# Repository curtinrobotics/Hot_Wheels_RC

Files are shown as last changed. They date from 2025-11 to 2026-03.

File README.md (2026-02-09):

# Hot_Wheels_RC

Welcome to the **Hot Wheels** project for Curtin Robotics club (CRoC)

This repository contains Arduino, ESP32, C++ codebases, hardware design, mechanical/electrical schematics.

---

## Project Structure

```
Hot_Wheels_RC/
├── archive/                    -> archival assests, may be still relevant
├── docs/                       -> Documentation for the project
├── hardware_design/            -> CAD and schematic files for the hardware components
│   ├── Hot_Wheels_3d_model/    -> 3D model exported files (e.g., .stl, .step) for manufacturing and prototyping
│   └── Hot_Wheels_3d_model.f3d -> Fusion 360 CAD file (requires Fusion 360 to open)
├── Hot_Wheels_arduino_firmware/ -> Arduino firmware source code
```

## Collaboration Guidelines

To ensure smooth teamwork:

- **Commit, pull, and push frequently** to keep everyone on the same page.
- **Create a branch** for any experimental or testing-specific changes. Once stable, we can discuss merging them into the main codebase.
- If you have questions, feel free to reach out to Aron or Joshan

---

Contributors:  
- **Shea, Aron**

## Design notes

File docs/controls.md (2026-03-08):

# Controls

Left joystick (left and right): steering left and right

RT/R3: accelerate

LT/L3: reverse

Steering trim

LB/L1: trim left

RB/R1: trim right

D-pad up: reset trim

LB/L1 + RB/R1 + D-pad up: factory reset saved trim

*Note: steering trim is saved and restored after reboot.*

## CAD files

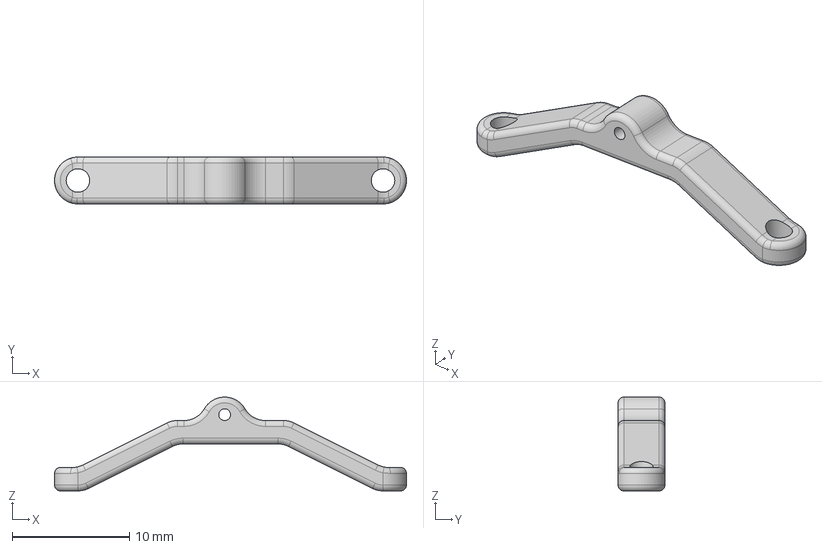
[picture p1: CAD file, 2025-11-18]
hardware_design/Hot_Wheels_3d_model/TieRod.step
30.0 x 4.00 x 8.00 mm

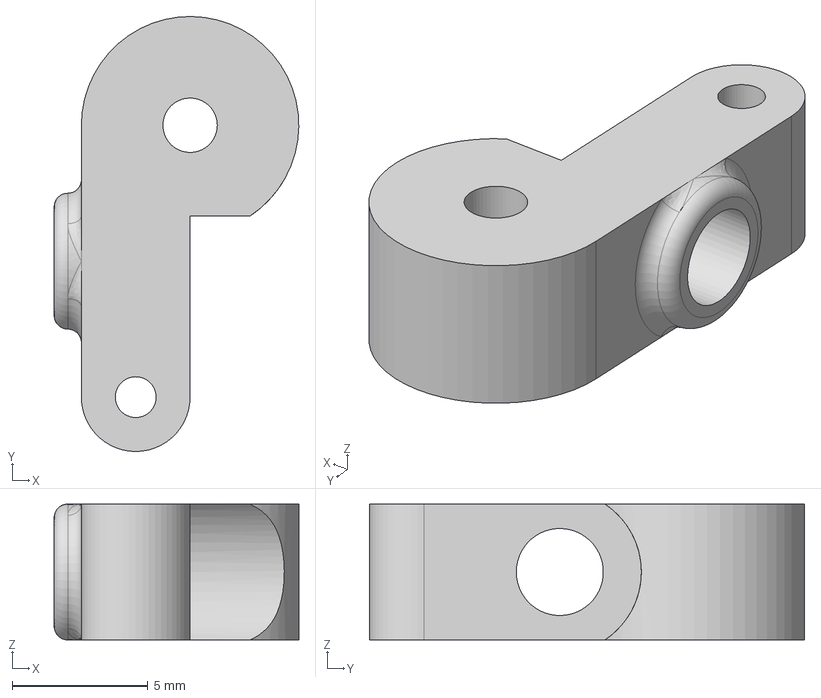
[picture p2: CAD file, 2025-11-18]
hardware_design/Hot_Wheels_3d_model/SteeringKnuckle.step
9.00 x 16.0 x 5.00 mm

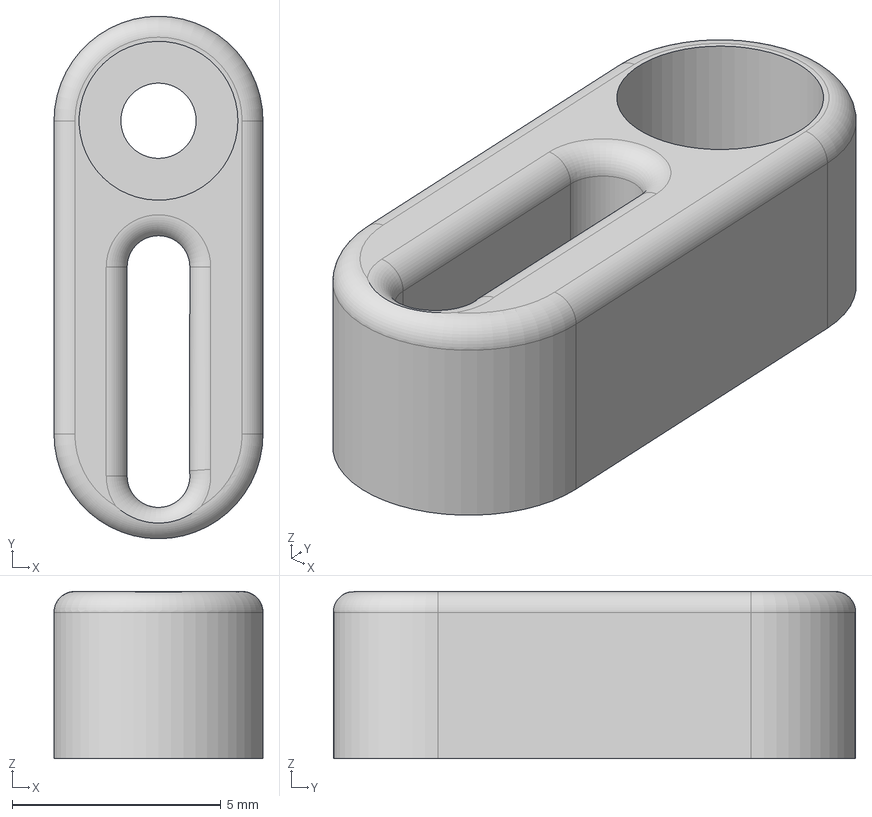
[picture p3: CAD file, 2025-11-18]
hardware_design/Hot_Wheels_3d_model/ServoArm.step
5.00 x 12.5 x 4.00 mm

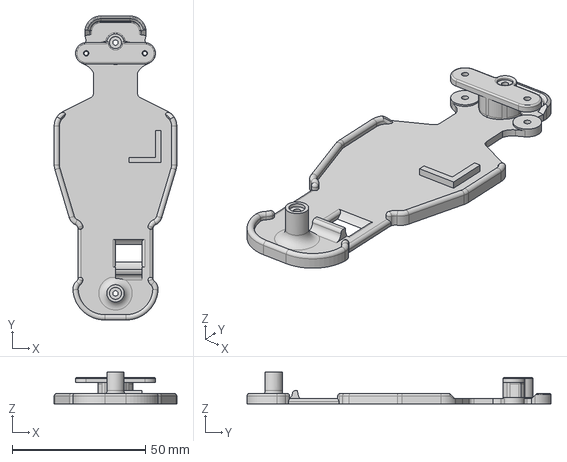
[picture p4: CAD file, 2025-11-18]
hardware_design/Hot_Wheels_3d_model/Body.step
46.0 x 114.0 x 12.0 mm

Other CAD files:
hardware_design/Hot_Wheels_3d_model.f3d

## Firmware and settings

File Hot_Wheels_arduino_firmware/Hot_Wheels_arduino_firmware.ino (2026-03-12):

#include <Bluepad32.h>
#include <Preferences.h>

Preferences prefs;
const char* NVS_NAMESPACE = "hwrc";
const char* NVS_KEY_STEER_TRIM = "trim";

const int servoPin = 9;
const int Forward = 12;
const int Back = 11;

// PWM Configuration for motors
const int PWM_FREQ = 5000;     // 5 KHz PWM frequency for motors
const int PWM_RESOLUTION = 8;  // 8-bit resolution (0-255)
const int FORWARD_PWM_CHANNEL = 0;
const int BACK_PWM_CHANNEL = 1;

// PWM Configuration for servo
const int SERVO_PWM_CHANNEL = 2;
const int SERVO_PWM_FREQ = 50;        // 50 Hz for standard servo
const int SERVO_PWM_RESOLUTION = 14;  // 14-bit for servo control

ControllerPtr myController = nullptr;
int Drive = 0;
int Reverse = 0;
int angle = 90;

// --- Steering trim (LB/RB) ---
int STEERING_TRIM_DEG = 0;          // applied to steering angle (degrees)
const int TRIM_STEP_DEG = 1;       // change per button press
const int TRIM_LIMIT_DEG = 90;     // max +/- trim from center
const bool TRIM_LATCH_START_STATE = false; // set both latches true/false at start

// Setup TRIM latch
bool lastTrimLB = TRIM_LATCH_START_STATE;
bool lastTrimRB = TRIM_LATCH_START_STATE;
bool lastDpadUp = TRIM_LATCH_START_STATE;
bool lastTrimFactoryResetCombo = TRIM_LATCH_START_STATE;

const int DEADZONE = 30;
const int SPEED_LIMIT_PERCENT = 100;  // Limit speed to 40% of max

// Trigger threshold and mapping
const int TRIGGER_DEADZONE = 10;
const int TRIGGER_MAX = 1023;

// Servo pulse timing (in microseconds)
const int SERVO_MIN_US = 1000;
const int SERVO_MAX_US = 2000;

// Steering limit (degrees from center=90). Example: 30 -> range 60..120
const int STEER_LIMIT_DEG = 90;

static void loadSteeringTrim() {
  STEERING_TRIM_DEG = prefs.getInt(NVS_KEY_STEER_TRIM, 0);
  STEERING_TRIM_DEG = constrain(STEERING_TRIM_DEG, -TRIM_LIMIT_DEG, TRIM_LIMIT_DEG);
  Serial.printf("Loaded steering trim: %+d deg\n", STEERING_TRIM_DEG);
}

static void saveSteeringTrim() {
  STEERING_TRIM_DEG = constrain(STEERING_TRIM_DEG, -TRIM_LIMIT_DEG, TRIM_LIMIT_DEG);
  prefs.putInt(NVS_KEY_STEER_TRIM, STEERING_TRIM_DEG);
}

void onConnectedController(ControllerPtr ctl) {
  if (myController == nullptr) {
    Serial.print("CALLBACK: Controller is connected, index=");
    Serial.println(ctl->index());
    myController = ctl;

    // Initialize trim latch state on connect
    lastTrimLB = TRIM_LATCH_START_STATE;
    lastTrimRB = TRIM_LATCH_START_STATE;
    lastDpadUp = TRIM_LATCH_START_STATE;
    lastTrimFactoryResetCombo = TRIM_LATCH_START_STATE;

    ctl->setColorLED(0, 255, 0);
  }
}

void onDisconnectedController(ControllerPtr ctl) {
  if (myController == ctl) {
    Serial.print("CALLBACK: Controller is disconnected from index=");
    Serial.println(ctl->index());

    angle = 90;

    // Initialize trim latch state on connect
    lastTrimLB = TRIM_LATCH_START_STATE;
    lastTrimRB = TRIM_LATCH_START_STATE;
    lastDpadUp = TRIM_LATCH_START_STATE;
    lastTrimFactoryResetCombo = TRIM_LATCH_START_STATE;

    // Stop motors when controller disconnects
    ledcWrite(FORWARD_PWM_CHANNEL, 0);
    ledcWrite(BACK_PWM_CHANNEL, 0);

    // Center servo
    setServoAngle(90);

    myController = nullptr;
  }
}

void processController() {
  if (myController && myController->isConnected() && myController->hasData()) {
    int32_t axisX = myController->axisX();
    int32_t throttle = myController->throttle();
    int32_t brake = myController->brake();

    // --- Steering trim via bumpers (edge-triggered) ---
    const bool lb = myController->l1();  // LB/L1
    const bool rb = myController->r1();  // RB/R1

    // D-pad up resets trim (edge-triggered)
    const bool dpadUp = (myController->dpad() & DPAD_UP) != 0;

    // Factory reset combo: LB + RB + D-pad Up clears saved trim (edge-triggered)
    const bool trimFactoryResetCombo = lb && rb && dpadUp;

    bool trimChanged = false;

    if (trimFactoryResetCombo && !lastTrimFactoryResetCombo) {
      STEERING_TRIM_DEG = 0;
      prefs.remove(NVS_KEY_STEER_TRIM);
      Serial.println("Steering trim factory reset: cleared saved value");
    } else {

      if (lb && !lastTrimLB) {
        STEERING_TRIM_DEG += TRIM_STEP_DEG;
        STEERING_TRIM_DEG = constrain(STEERING_TRIM_DEG, -TRIM_LIMIT_DEG, TRIM_LIMIT_DEG);
        Serial.printf("Steering trim: %+d deg\n", STEERING_TRIM_DEG);
        trimChanged = true;
      }
      if (rb && !lastTrimRB) {
        STEERING_TRIM_DEG -= TRIM_STEP_DEG;
        STEERING_TRIM_DEG = constrain(STEERING_TRIM_DEG, -TRIM_LIMIT_DEG, TRIM_LIMIT_DEG);
        Serial.printf("Steering trim: %+d deg\n", STEERING_TRIM_DEG);
        trimChanged = true;
      }

      if (dpadUp && !lastDpadUp) {
        STEERING_TRIM_DEG = 0;
        Serial.println("Steering trim reset: 0 deg");
        trimChanged = true;
      }

      if (trimChanged) {
        saveSteeringTrim();
      }
    }

    lastTrimLB = lb;
    lastTrimRB = rb;
    lastDpadUp = dpadUp;
    lastTrimFactoryResetCombo = trimFactoryResetCombo;

    if (abs(axisX) < DEADZONE) {
      axisX = 0;
    }

    Drive = throttle;
    Reverse = brake;

    const int leftLimit = 90 + STEER_LIMIT_DEG;
    const int rightLimit = 90 - STEER_LIMIT_DEG;

    angle = map(axisX, -511, 512, leftLimit, rightLimit);

    // Apply trim, then clamp to steering limits
    angle += STEERING_TRIM_DEG;
    angle = constrain(angle, rightLimit, leftLimit);
  }
}

void setServoAngle(int angle) {
  // Map angle (0-180) to microseconds (1000-2000)
  int pulseWidth = map(angle, 0, 180, SERVO_MIN_US, SERVO_MAX_US);

  // Calculate duty cycle for 14-bit resolution at 50Hz
  // At 50Hz, period = 20ms = 20000 microseconds
  // For 14-bit: max value = 16383 (2^14 - 1)
  // Duty cycle = (pulseWidth / 20000) * 16383
  uint32_t dutyCycle = ((uint32_t)pulseWidth * 16384) / 20000;

  ledcWrite(SERVO_PWM_CHANNEL, dutyCycle);
}

void updateMotorSpeed() {
  int forwardSpeed = 0;
  int reverseSpeed = 0;
  
  // Calculate max speed based on limit
  int maxSpeed = (255 * SPEED_LIMIT_PERCENT) / 100;
  
  // Map trigger values to PWM duty cycle with speed limit
  if (Drive >= TRIGGER_DEADZONE) {
    forwardSpeed = map(Drive, TRIGGER_DEADZONE, TRIGGER_MAX, 0, maxSpeed);
    forwardSpeed = constrain(forwardSpeed, 0, maxSpeed);
  }
  
  if (Reverse >= TRIGGER_DEADZONE) {
    reverseSpeed = map(Reverse, TRIGGER_DEADZONE, TRIGGER_MAX, 0, maxSpeed);
    reverseSpeed = constrain(reverseSpeed, 0, maxSpeed);
  }
  
  // Prevent both motors from running simultaneously (prioritize forward)
  if (forwardSpeed > 0 && reverseSpeed > 0) {
    reverseSpeed = 0;
  }
  
  // Update PWM outputs
  ledcWrite(FORWARD_PWM_CHANNEL, forwardSpeed);
  ledcWrite(BACK_PWM_CHANNEL, reverseSpeed);
}

void setup() {
  Serial.begin(115200);
  Serial.println("Starting RC Car Controller...");

  prefs.begin(NVS_NAMESPACE, false);
  loadSteeringTrim();

  BP32.setup(&onConnectedController, &onDisconnectedController);
  BP32.forgetBluetoothKeys();

  // Setup PWM for motor control
  ledcSetup(FORWARD_PWM_CHANNEL, PWM_FREQ, PWM_RESOLUTION);
  ledcSetup(BACK_PWM_CHANNEL, PWM_FREQ, PWM_RESOLUTION);
  ledcAttachPin(Forward, FORWARD_PWM_CHANNEL);
  ledcAttachPin(Back, BACK_PWM_CHANNEL);

  // Setup PWM for servo control
  ledcSetup(SERVO_PWM_CHANNEL, SERVO_PWM_FREQ, SERVO_PWM_RESOLUTION);
  ledcAttachPin(servoPin, SERVO_PWM_CHANNEL);

  // Initialize motors to stopped
  ledcWrite(FORWARD_PWM_CHANNEL, 0);
  ledcWrite(BACK_PWM_CHANNEL, 0);

  // Center servo
  angle = 90;
  setServoAngle(angle);

  Serial.println("Setup complete. Waiting for Xbox controller...");
  Serial.println("Use left joystick X-axis for steering");
  Serial.println("Use triggers for variable speed control");
  Serial.printf("Speed limited to %d%% of maximum\n", SPEED_LIMIT_PERCENT);
}

void loop() {
  BP32.update();
  processController();

  // Update motor speeds based on trigger values
  updateMotorSpeed();

  // Update servo position using hardware PWM
  setServoAngle(angle);

  delay(1);
}

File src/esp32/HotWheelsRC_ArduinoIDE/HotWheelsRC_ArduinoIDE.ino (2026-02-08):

/*
 * ESP32-S3 RC Car Steering Control
 * Uses Bluepad32 library with Xbox controller
 * Uses manual PWM control for servo (compatible with Bluepad32 board definition)
 */

#include <Bluepad32.h>

// Servo setup
const int SERVO_PIN = 9;  // Change to your actual servo pin

// Controller variables
ControllerPtr myController = nullptr;

// Servo control variables
int currentAngle = 90;     // Start at center position
int targetAngle = 90;      // Target angle from joystick
const int DEADZONE = 50;   // Joystick deadzone to prevent jitter
bool INVERT_STEERING = false;

// PWM timing variables
unsigned long lastPWMTime = 0;
const int PWM_PERIOD = 20; // 20ms period for 50Hz

void onConnectedController(ControllerPtr ctl) {
    if (myController == nullptr) {
        Serial.print("CALLBACK: Controller is connected, index=");
        Serial.println(ctl->index());
        myController = ctl;
        
        // Optional: Set controller LED color to indicate connection
        ctl->setColorLED(0, 255, 0); // Green LED
    }
}

void onDisconnectedController(ControllerPtr ctl) {
    if (myController == ctl) {
        Serial.print("CALLBACK: Controller is disconnected from index=");
        Serial.println(ctl->index());
        
        // Return servo to center when controller disconnects
        currentAngle = 90;
        targetAngle = 90;
        
        myController = nullptr;
    }
}

void setup() {
    Serial.begin(115200);
    Serial.println("Starting RC Car Controller...");
    
    // Initialize Bluepad32
    BP32.setup(&onConnectedController, &onDisconnectedController);
    // BP32.forgetBluetoothKeys(); // Remove this line if you don't want to forget paired devices
    
    // Initialize servo pin
    pinMode(SERVO_PIN, OUTPUT);
    digitalWrite(SERVO_PIN, LOW);
    
    // Set initial position
    currentAngle = 90;
    targetAngle = 90;
    
    Serial.println("Setup complete. Waiting for Controller...");
    Serial.println("Tip: Use left joystick X-axis for steering");
}

float angleToERS(int angle) {
    // Convert angle (0-180) to pulse width in milliseconds
    // Your servo: 0.5ms = 0°, 1.45ms = 90°, 2.4ms = 180°
    return map(angle, 0, 180, 500, 2400) / 1000.0;
}

void sendServoPulse(int angle) {
    float pulseWidthMs = angleToERS(angle);
    
    digitalWrite(SERVO_PIN, HIGH);
    delayMicroseconds(pulseWidthMs * 1000);  // Convert ms to microseconds
    digitalWrite(SERVO_PIN, LOW);
}

void processController() {
    if (myController && myController->isConnected() && myController->hasData()) {
        
        // Get left joystick X-axis (-511 to +512)
        int32_t axisX = myController->axisX();
        
        // Apply deadzone to prevent servo jitter when joystick is centered
        if (abs(axisX) < DEADZONE) {
            axisX = 0;
        }
        
        // Map joystick input to servo angle (0-180 degrees)
        if (abs(axisX) < DEADZONE) {
            targetAngle = 90;
            } else {
                if (INVERT_STEERING)
                    targetAngle = map(axisX, -511, 511, 0, 180);
                else
                    targetAngle = map(axisX, -511, 511, 180, 0);
            }
        
        // Optional: Limit servo range for your specific setup
        // targetAngle = map(axisX, -511, 512, 60, 120); // Limited range
        
        // Smooth servo movement to prevent jerky steering
        if (abs(targetAngle - currentAngle) > 2) { // Only update if significant change
            currentAngle = (currentAngle * 3 + targetAngle) / 4; // Simple smoothing
            
            // Debug output
            Serial.print("Joystick X: ");
            Serial.print(axisX);
            Serial.print(" -> Servo Angle: ");
            Serial.println(currentAngle);
        }
    }
}

void loop() {
    // This call fetches all the controller's data
    BP32.update();
    
    // Process controller input if connected
    processController();
    
    // Send PWM pulse every 20ms (50Hz)
    unsigned long currentTime = millis();
    if (currentTime - lastPWMTime >= PWM_PERIOD) {
        sendServoPulse(currentAngle);
        lastPWMTime = currentTime;
    }
    
    // Small delay to prevent overwhelming the system
    delay(1);
}

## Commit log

2025-11-18 3D Model STEP Files
    [Body.step, ServoArm.step, SteeringKnuckle.step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]
2025-11-18 ESP32S3 Arduino IDE Code
2026-02-08 corrected servo pin to current prototype
    [HotWheelsRC_ArduinoIDE.ino]
2026-02-08 flipped servo orientation
2026-02-08 added INVERT_STEERING to quickly flip the steering rotation
    [HotWheelsRC_ArduinoIDE.ino]
2026-02-08 changed serial print to say waiting for Controller to prevent misconceptions about firmware only working on xbox controllers
    [HotWheelsRC_ArduinoIDE.ino]
2026-02-09 Added new arduino firmware pwm-speed-control
2026-02-09 moved directories out of src into root for easier navigation
    [Body.step, HotWheels.f3d, ServoArm.step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]
2026-02-09 tidied up hardware_design assests
    [Body.step, Hot_Wheels_3d_model.f3d, ServoArm.step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]
2026-02-09 added steering limit to prevent servo from dislodging its own gears
    [Hot_Wheels_arduino_firmware.ino]
2026-02-09 intial throttle firmware
2026-02-15 maxed out steering and speed limit
2026-03-08 added digital steering trim
2026-03-08 added persistent trim values that are restored even after power off
2026-03-08 added steering limit for archival firmware
2026-03-12 fixed pref not being defined
    [Hot_Wheels_arduino_firmware.ino]
